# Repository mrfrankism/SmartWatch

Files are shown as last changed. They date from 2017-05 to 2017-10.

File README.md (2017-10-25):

## Welcome to my Smart Watch Project

This Project was started May 2017 and is still being worked on.
For more detailed Information check out the [wiki](https://github.com/mrfrankism/SmartWatch/wiki)

### Current Status:
* Currently the watch has undergone 2 prototypes.
* 2nd Prototype spin:


* The 2nd prototype was fabbed with the incorrecct package for the atmega328, so the 3rd spin will fix this issue without adding new       features for now
* Case for the watch is being designed to be 3D printed

### Initial goals for this project are:
* Working screen
* Actual simple watch functionality
* Computer to watch communication (SPI, UART)
* Bluetooth connectivity to phone 
* Notifications
* Probably going to need to make an app for full bluetooth-notification functionality
* Decent battery life (6 hours)
* Ability to charge easily from usb

### Extra goals:
* SOS signal - Being able to send a text with GPS coordinates to emergency contact, using only the watch 
* LTE connectivity
* Accelerometer
* Gyro
* Wifi?
* GPS

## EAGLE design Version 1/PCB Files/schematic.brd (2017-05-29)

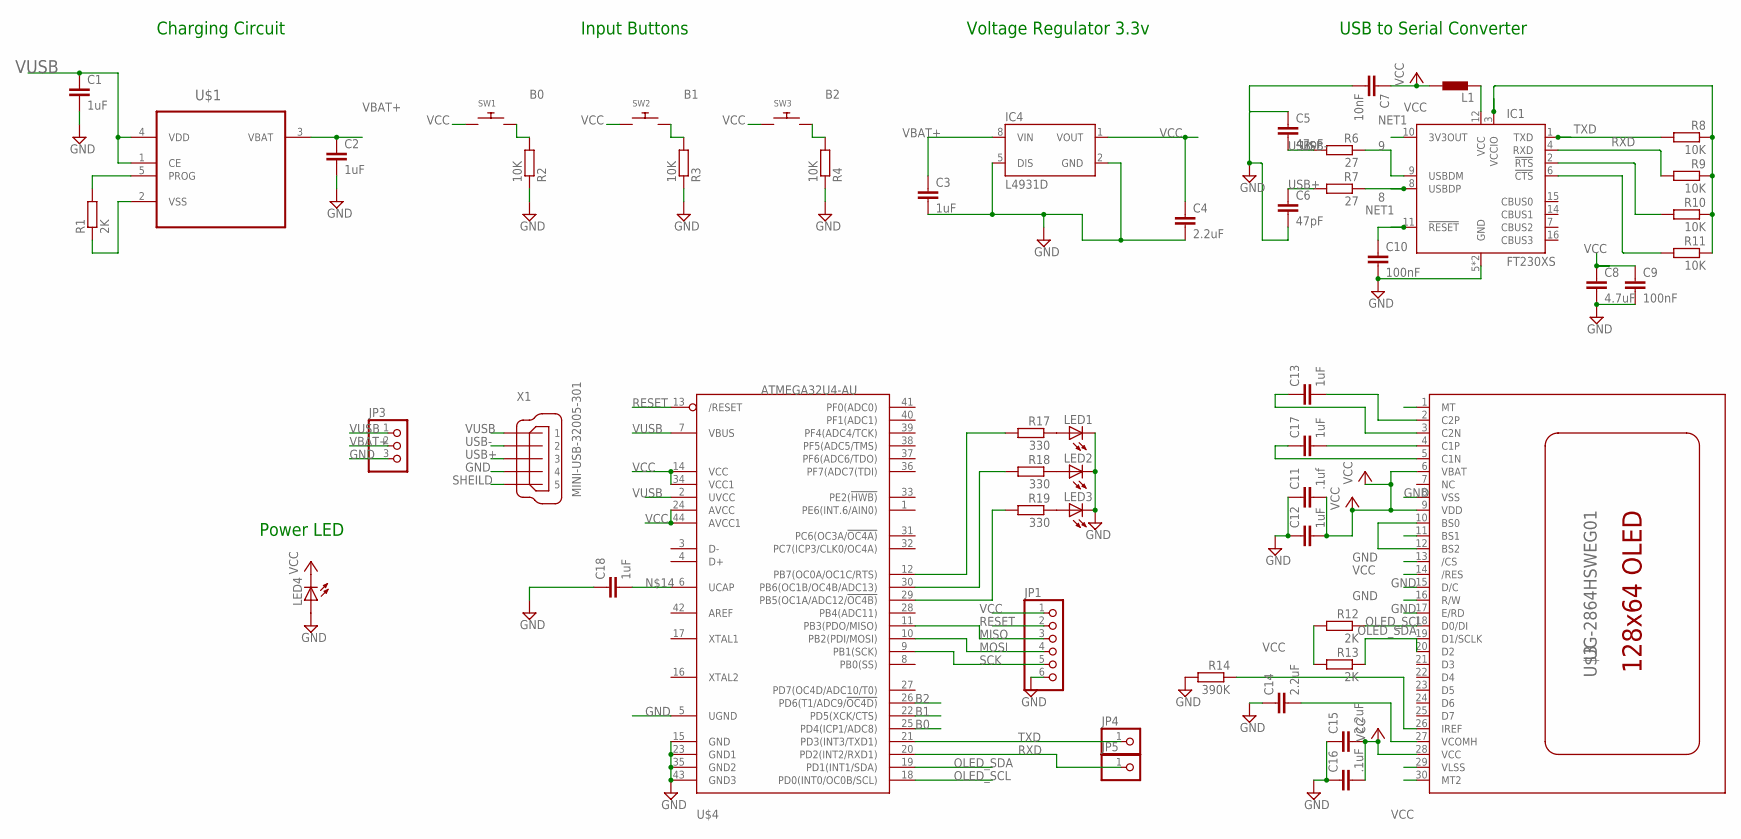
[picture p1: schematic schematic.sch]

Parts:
C1, C2, C3, C12, C13, C17, C18: 1uF; C0504
C4, C14, C15: 2.2uF; C0504
C5, C6: 47pF; C0504
C7: 10nF; C0504
C8: 4.7uF; C0504
C9, C10: 100nF; C0504
C11: .1uf; C0504
C16: .1uF; C0504
IC1: FT230XS; SSOP16
IC4: L4931D; SO08
JP1: PINHD-1X6B; 1X06-BIG
JP3: PINHD-1X3; 1X03
JP4, JP5: PINHD-1X1; 1X01
L1: BLM15HB221SN1; 0402
LED1, LED2, LED3, LED4: LEDSMT1206; 1206
R1, R12, R13: 2K; R0603
R2, R3, R4, R8, R9, R10, R11: 10K; R0603
R6, R7: 27; R0603
R14: 390K; R0603
R17, R18, R19: 330; R0603
SW1, SW2, SW3: SWITCH_PUSHBUTTONSOFTTOUCHSMD_SJ; PUSHBUTTON_SMD_SJ
U$1: MCP73812T-420I/OT; SOT95P270X145-5N
U$3: UG-2864HSWEG01; 1X30-0.7MM
U$4: ATMEGA32U4-AU; TQFP44
X1: MINI-USB-32005-301; 32005-301

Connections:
8: IC1.8 (USBDP), R7.1
9: IC1.9 (USBDM), R6.1
B0: R2.2, SW1.P$2, U$4.25 (PD4(ICP1/ADC8))
B1: R3.2, SW2.P$2, U$4.22 (PD5(XCK/CTS))
B2: R4.2, SW3.P$2, U$4.26 (PD6(T1/ADC9/!OC4D))
FTDI_VCC: IC1.12 (VCC), L1.1
GND: C1.2, C2.2, C3.2, C4.2, C5.1, C6.2, C7.2, C8.2, C9.2, C10.2, C11.1, C12.1, C14.1, C15.1, C16.1, C18.1, IC1.5 (GND), IC1.13 (GND), IC4.2 (GND), IC4.5 (DIS), JP1.6, JP3.3, LED1.C, LED2.C, LED3.C, LED4.A, R2.1, R3.1, R4.1, R14.2, U$3.1 (MT), U$3.8 (VSS), U$3.10 (BS0), U$3.12 (BS2), U$3.13 (/CS), U$3.15 (D/C), U$3.16 (R/W), U$3.17 (E/RD), U$3.29 (VLSS), U$3.30 (MT2), U$4.5 (UGND), U$4.15 (GND), U$4.23 (GND1), U$4.35 (GND2), U$4.43 (GND3), X1.4
MISO: JP1.3, U$4.11 (PB3(PDO/MISO))
MOSI: JP1.4, U$4.10 (PB2(PDI/MOSI))
unnamed: R1.2, U$1.5 (PROG)
unnamed: R1.1, U$1.2 (VSS)
unnamed: C14.2, U$3.27 (VCOMH)
unnamed: IC1.2 (!RTS), R10.2
unnamed: C13.2, U$3.2 (C2P)
unnamed: IC1.6 (!CTS), R11.2
unnamed: R14.1, U$3.26 (IREF)
unnamed: C13.1, U$3.3 (C2N)
unnamed: C17.2, U$3.4 (C1P)
unnamed: C17.1, U$3.5 (C1N)
unnamed: C18.2, U$4.6 (UCAP)
unnamed: LED1.A, R17.1
unnamed: LED2.A, R18.1
unnamed: LED3.A, R19.1
unnamed: R19.2, U$4.29 (PB5(OC1A/ADC12/!OC4B))
unnamed: R18.2, U$4.30 (PB6(OC1B/OC4B/ADC13))
unnamed: R17.2, U$4.12 (PB7(OC0A/OC1C/RTS))
NET1: C10.1, IC1.3 (VCCIO), IC1.10 (3V3OUT), IC1.11 (!RESET), R8.1, R9.1, R10.1, R11.1
OLED_SCL: R12.1, U$3.18 (D0/DI), U$4.18 (PD0(INT0/OC0B/SCL))
OLED_SDA: R13.1, U$3.19 (D1/SCLK), U$3.20 (D2), U$4.19 (PD1(INT1/SDA))
RESET: JP1.2, U$4.13 (/RESET)
RXD: IC1.4 (RXD), JP5.1, R9.2, U$4.20 (PD2(INT2/RXD1))
SCK: JP1.5, U$4.9 (PB1(SCK))
SHEILD: X1.5
TXD: IC1.1 (TXD), JP4.1, R8.2, U$4.21 (PD3(INT3/TXD1))
USB+: C6.1, R7.2, X1.3
USB-: C5.2, R6.2, X1.2
VBAT+: C2.1, C3.1, IC4.8 (VIN), JP3.2, U$1.3 (VBAT)
VCC: C4.1, C7.1, C8.1, C9.1, C11.2, C12.2, C15.2, C16.2, IC4.1 (VOUT), JP1.1, L1.2, LED4.C, R12.2, R13.2, SW1.P$1, SW2.P$1, SW3.P$1, U$3.6 (VBAT), U$3.9 (VDD), U$3.11 (BS1), U$3.14 (/RES), U$3.28 (VCC), U$4.14 (VCC), U$4.24 (AVCC), U$4.34 (VCC1), U$4.44 (AVCC1)
VUSB: C1.1, JP3.1, U$1.1 (CE), U$1.4 (VDD), U$4.2 (UVCC), U$4.7 (VBUS), X1.1

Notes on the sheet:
Charging Circuit
Input Buttons
Voltage Regulator 3.3v
USB to Serial Converter
Power LED

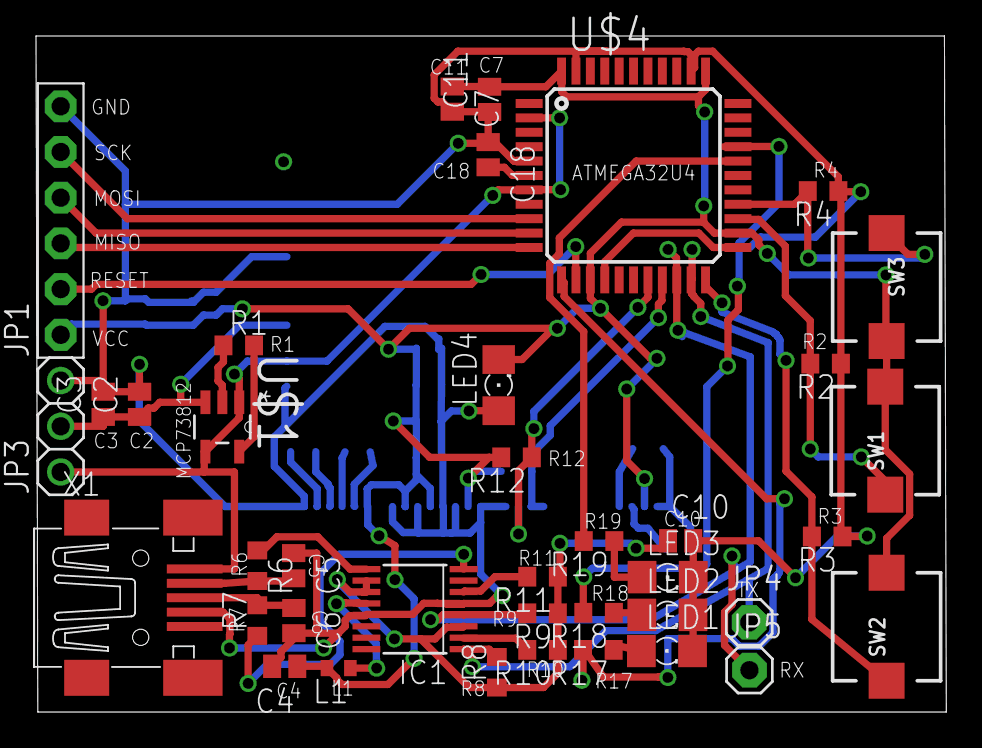
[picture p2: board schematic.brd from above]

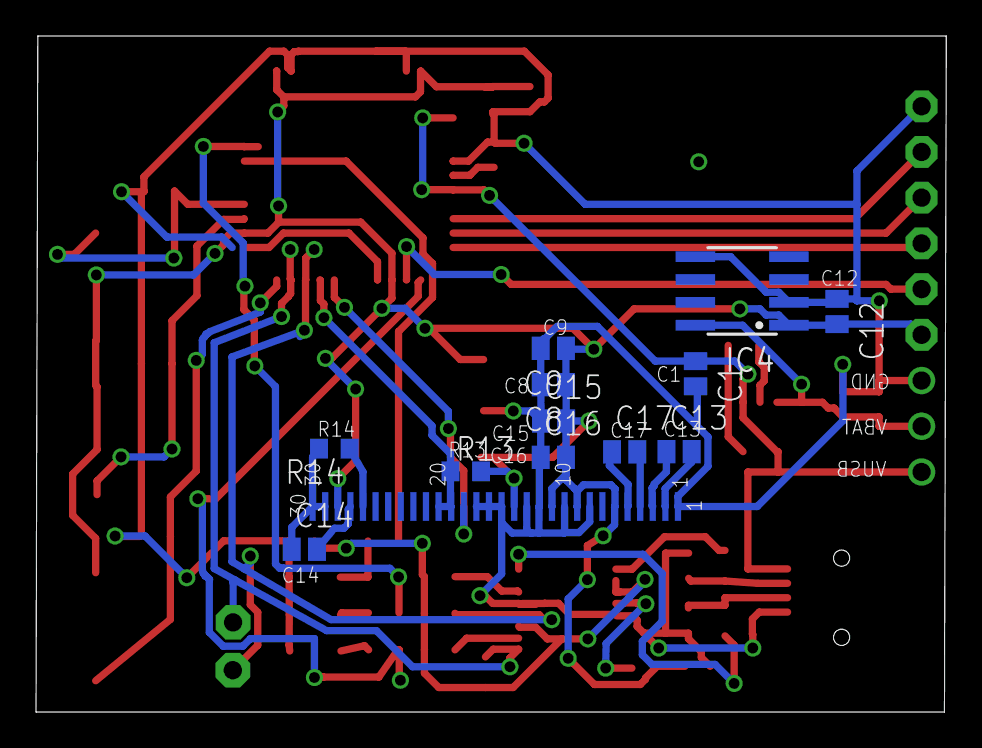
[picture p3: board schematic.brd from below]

Board: 2 copper layers, 50.6 x 37.6 mm, 52 parts (13 on the bottom side), 38 nets.

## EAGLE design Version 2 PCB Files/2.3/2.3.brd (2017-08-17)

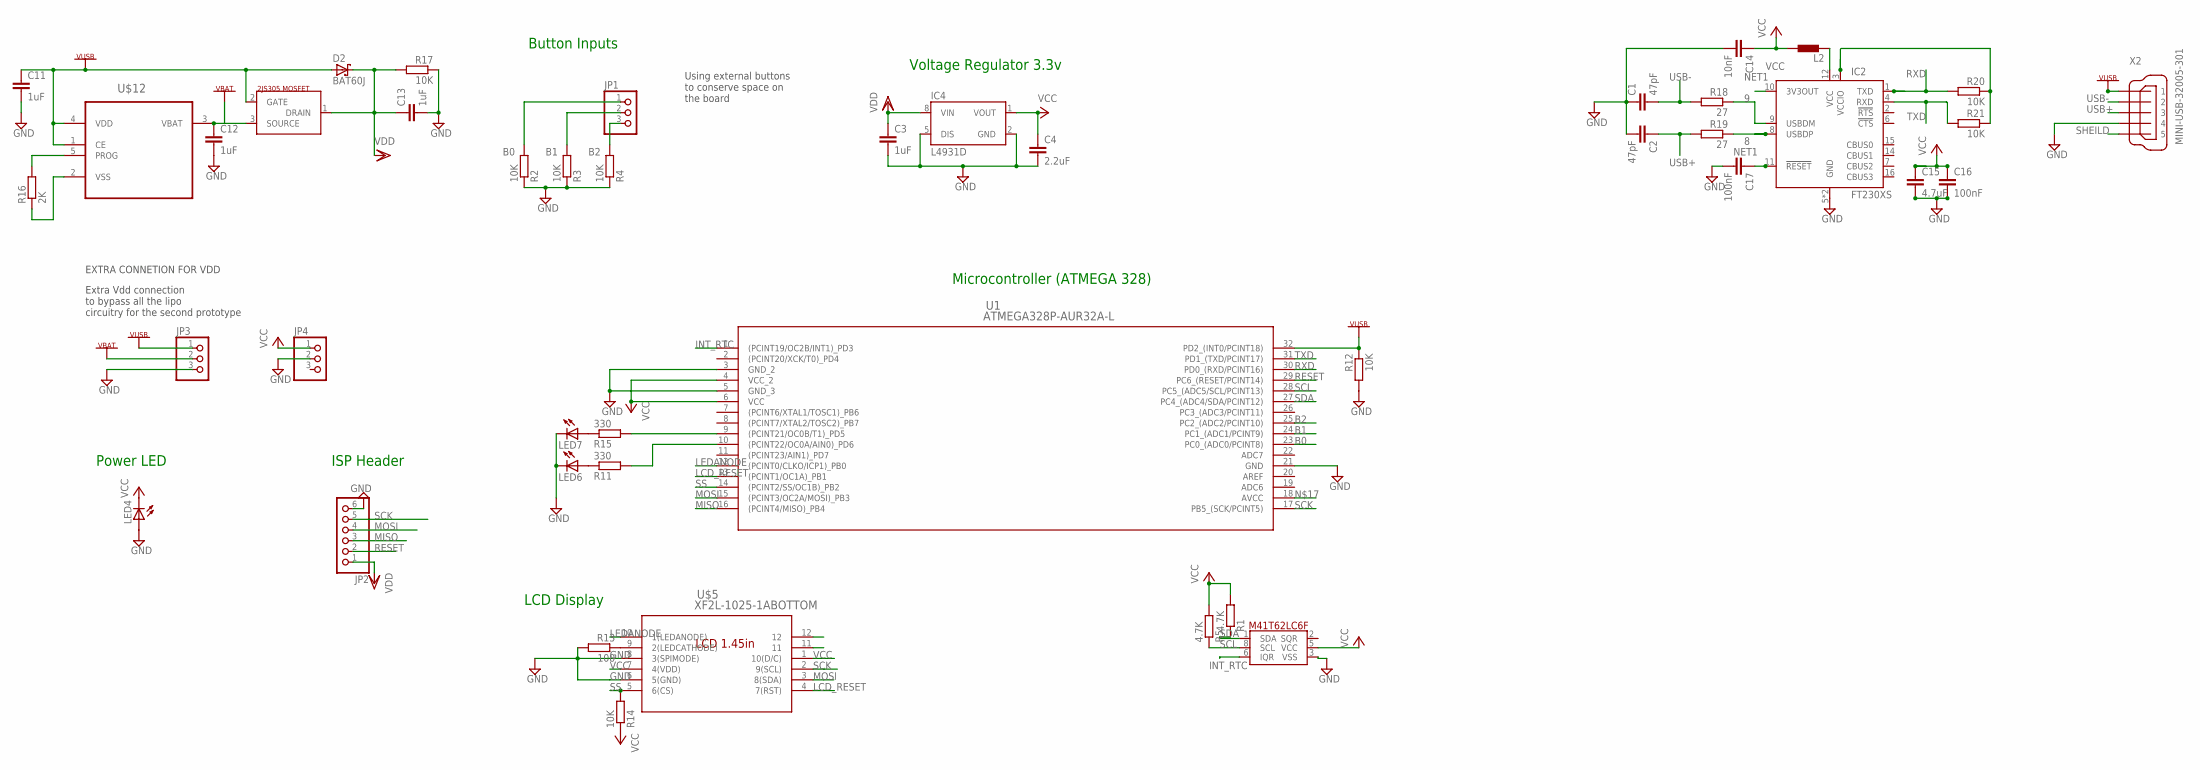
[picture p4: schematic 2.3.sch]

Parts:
C1, C2: 47pF; C0603K
C3, C11, C12, C13: 1uF; C0603K
C4: 2.2uF; C0603K
C14: 10nF; C0603K
C15: 4.7uF; C0603K
C16, C17: 100nF; C0603K
D2: BAT60J; SOD323_ST
IC2: FT230XS; SSOP16
IC4: L4931D; SO08
JP1, JP3, JP4: PINHD-1X3CB; 1X03-CLEANBIG
JP2: PINHD-1X6B; 1X06-BIG
L2: BLM15HB221SN1; 0402
LED4, LED6, LED7: LEDSMT1206; 1206
R1, R5: 4.7K; R0603
R2, R3, R4, R12, R14, R17, R20, R21: 10K; R0603
R11, R15: 330; R0603
R13: 100; R0603
R16: 2K; R0603
R18, R19: 27; R0603
U1: ATMEGA328P-AUR32A-L; 32A-L
U$1: M41T62LC6F; LCC-8
U$5: XF2L-1025-1ABOTTOM; CON10_1X10_DBR_XF2L
U$12: MCP73812T-420I/OT; SOT95P270X145-5N
U$13: 2JS305; SOT346-R
X2: MINI-USB-32005-301; 32005-301

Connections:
8: IC2.8 (USBDP), R19.1
9: IC2.9 (USBDM), R18.1
B0: JP1.1, R2.2, U1.23 (PC0_(ADC0/PCINT8))
B1: JP1.2, R3.2, U1.24 (PC1_(ADC1/PCINT9))
B2: JP1.3, R4.2, U1.25 (PC2_(ADC2/PCINT10))
GND: C1.1, C2.2, C3.2, C4.2, C11.2, C12.2, C13.2, C14.2, C15.2, C16.2, C17.2, IC2.5 (GND), IC2.13 (GND), IC4.2 (GND), IC4.5 (DIS), JP2.6, JP3.3, JP4.2, LED4.A, LED6.C, LED7.C, R2.1, R3.1, R4.1, R12.2, R13.2, R17.1, U1.3 (GND_2), U1.5 (GND_3), U1.21 (GND), U$1.3 (VSS), U$5.6 (5(GND)), U$5.8 (3(SPIMODE)), X2.4
INT_RTC: U1.1 ((PCINT19/OC2B/INT1)_PD3), U$1.6 (IQR)
LCD_RESET: U1.13 ((PCINT1/OC1A)_PB1), U$5.4 (7(RST))
LEDANODE: U1.12 ((PCINT0/CLKO/ICP1)_PB0), U$5.10 (1(LEDANODE))
MISO: JP2.3, U1.16 ((PCINT4/MISO)_PB4)
MOSI: JP2.4, U1.15 ((PCINT3/OC2A/MOSI)_PB3), U$5.3 (8(SDA))
unnamed: R13.1, U$5.9 (2(LEDCATHODE))
unnamed: IC2.12 (VCC), L2.1
unnamed: R15.2, U1.9 ((PCINT21/OC0B/T1)_PD5)
unnamed: R16.2, U$12.5 (PROG)
unnamed: R16.1, U$12.2 (VSS)
unnamed: LED6.A, R11.1
unnamed: LED7.A, R15.1
unnamed: R11.2, U1.10 ((PCINT22/OC0A/AIN0)_PD6)
NET1: C17.1, IC2.3 (VCCIO), IC2.10 (3V3OUT), IC2.11 (!RESET), R20.1, R21.1
RESET: JP2.2, U1.29 (PC6_(RESET/PCINT14))
RXD: IC2.1 (TXD), R20.2, U1.30 (PD0_(RXD/PCINT16))
SCK: JP2.5, U1.17 (PB5_(SCK/PCINT5)), U$5.2 (9(SCL))
SCL: R5.1, U1.28 (PC5_(ADC5/SCL/PCINT13)), U$1.8 (SCL)
SDA: R1.1, U1.27 (PC4_(ADC4/SDA/PCINT12)), U$1.1 (SDA)
SHEILD: X2.5
SS: R14.2, U1.14 ((PCINT2/SS/OC1B)_PB2), U$5.5 (6(CS))
TXD: IC2.4 (RXD), R21.2, U1.31 (PD1_(TXD/PCINT17))
USB+: C2.1, R19.2, X2.3
USB-: C1.2, R18.2, X2.2
VBAT: C12.1, JP3.2, U$12.3 (VBAT), U$13.3 (SOURCE)
VCC: C4.1, C14.1, C15.1, C16.1, IC4.1 (VOUT), JP4.1, L2.2, LED4.C, R1.2, R5.2, R14.1, U1.4 (VCC_2), U1.6 (VCC), U$1.5 (VCC), U$5.1 (10(D/C)), U$5.7 (4(VDD))
VDD: C3.1, C13.1, D2.C, IC4.8 (VIN), JP2.1, R17.2, U$13.1 (DRAIN)
VUSB: C11.1, D2.A, JP3.1, R12.1, U1.32 (PD2_(INT0/PCINT18)), U$12.1 (CE), U$12.4 (VDD), U$13.2 (GATE), X2.1

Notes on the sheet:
Button Inputs
Voltage Regulator 3.3v
Power LED
EXTRA CONNETION FOR VDD
Extra Vdd connection to bypass all the lipo circuitry for the second prototype
ISP Header
Microcontroller (ATMEGA 328)
LCD Display
Using external buttons to conserve space on the board

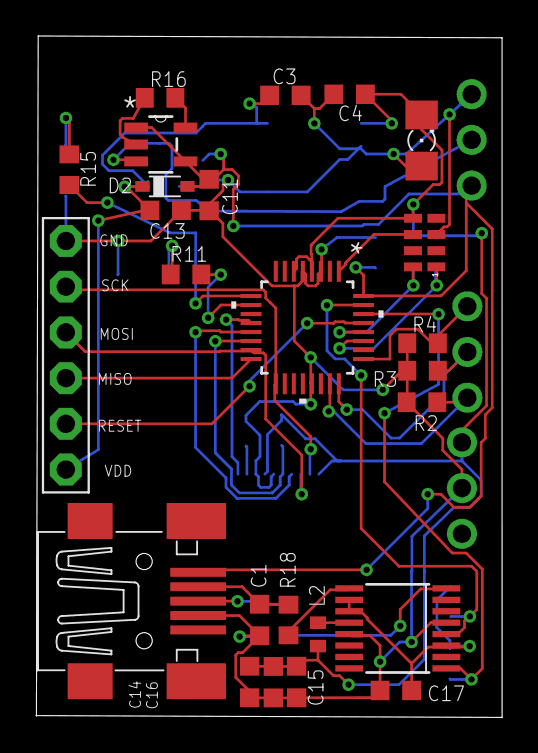
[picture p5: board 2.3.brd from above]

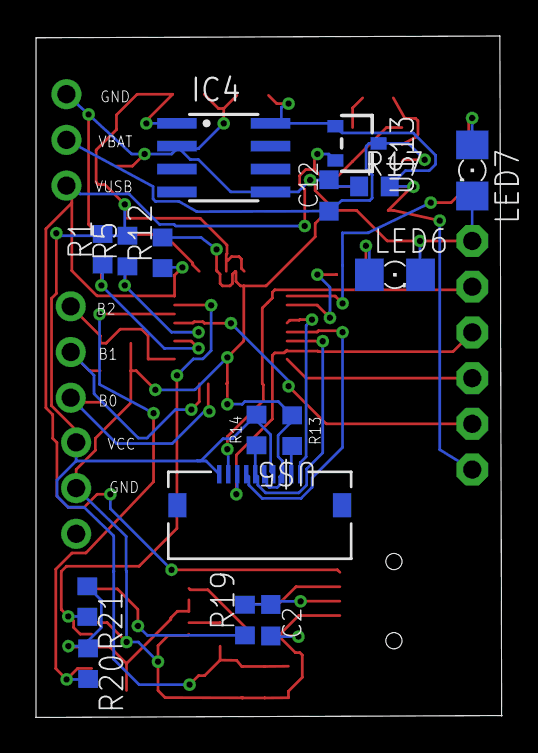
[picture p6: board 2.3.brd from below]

Board: 2 copper layers, 25.9 x 37.9 mm, 44 parts (16 on the bottom side), 33 nets.

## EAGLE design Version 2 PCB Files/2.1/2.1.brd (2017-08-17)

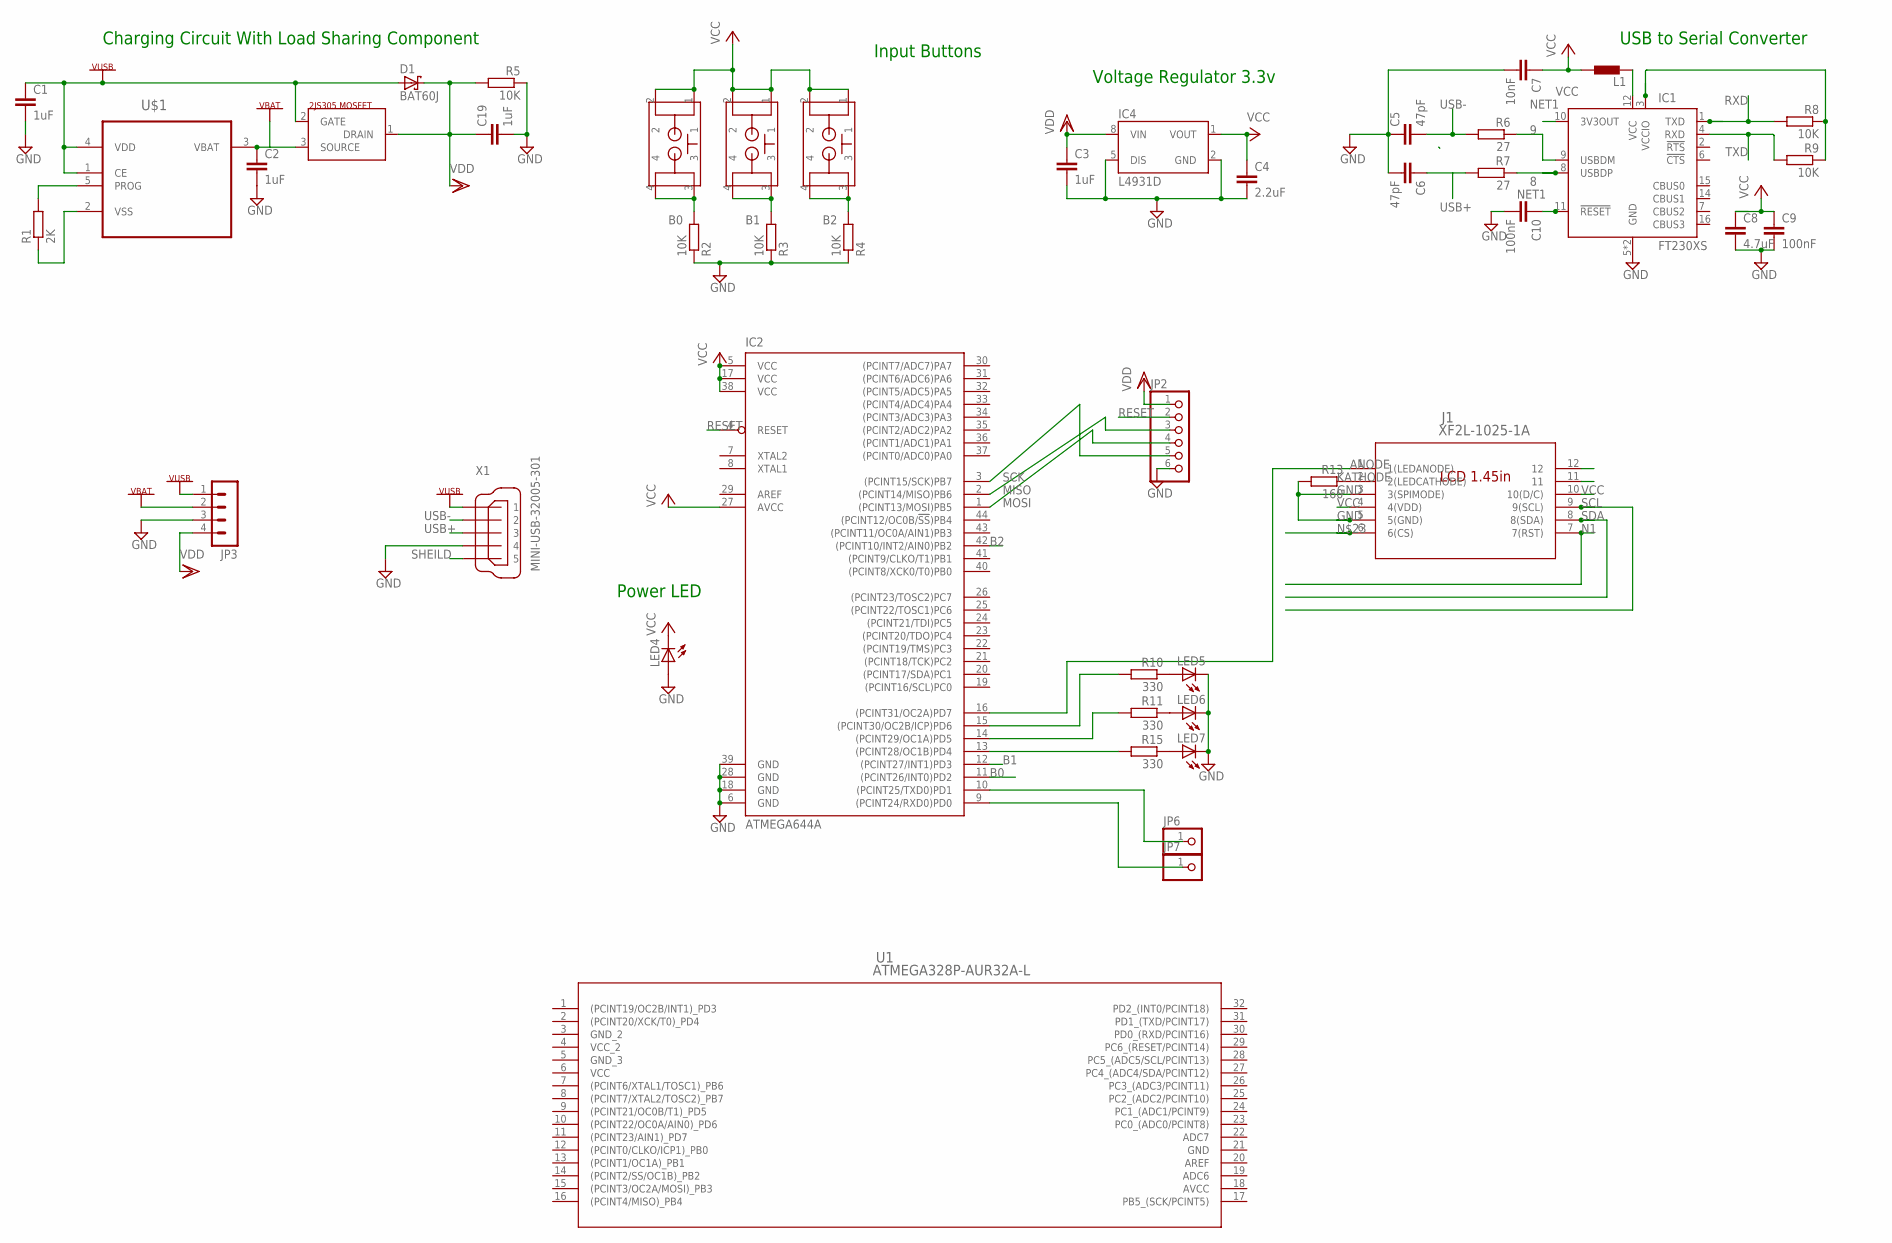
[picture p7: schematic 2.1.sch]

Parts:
C1, C2, C3, C19: 1uF; C0603K
C4: 2.2uF; C0603K
C5, C6: 47pF; C0603K
C7: 10nF; C0603K
C8: 4.7uF; C0603K
C9, C10: 100nF; C0603K
D1: BAT60J; SOD323_ST
IC1: FT230XS; SSOP16
IC2: ATMEGA644A; TQFP44
IC4: L4931D; SO08
J1: XF2L-1025-1A; CON10_1X10_DBR_XF2L
JP2: PINHD-1X6B; 1X06-BIG
JP3: MA04-1
JP6, JP7: PINHD-1X1; 1X01
L1: BLM15HB221SN1; 0402
LED4, LED5, LED6, LED7: LEDSMT1206; 1206
R1: 2K; R0603
R2, R3, R4, R5, R8, R9: 10K; R0603
R6, R7: 27; R0603
R10, R11, R15: 330; R0603
R13: 160; R0603
U1: ATMEGA328P-AUR32A-L; 32A-L
U$1: MCP73812T-420I/OT; SOT95P270X145-5N
U$2: 2JS305; SOT346-R
U$3, U$4, U$11: TL3315NF100Q; TL3315NF100Q-PACKAGE
X1: MINI-USB-32005-301; 32005-301

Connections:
8: IC1.8 (USBDP), R7.1
9: IC1.9 (USBDM), R6.1
ANODE: IC2.16 ((PCINT31/OC2A)PD7), J1.1 (1(LEDANODE))
AVCC: U1.18 (AVCC)
B0: IC2.11 ((PCINT26/INT0)PD2), R2.2, U$3.3, U$3.4
B1: IC2.12 ((PCINT27/INT1)PD3), R3.2, U$4.3, U$4.4
B2: IC2.42 ((PCINT10/INT2/AIN0)PB2), R4.2, U$11.3, U$11.4
FTDI_VCC: IC1.12 (VCC), L1.1
GND: C1.2, C2.2, C3.2, C4.2, C5.1, C6.2, C7.2, C8.2, C9.2, C10.2, C19.2, IC1.5 (GND), IC1.13 (GND), IC2.6 (GND), IC2.18 (GND), IC2.28 (GND), IC2.39 (GND), IC4.2 (GND), IC4.5 (DIS), J1.3 (3(SPIMODE)), J1.5 (5(GND)), JP2.6, JP3.3, LED4.A, LED5.C, LED6.C, LED7.C, R2.1, R3.1, R4.1, R5.1, R13.2, U1.21 (GND), X1.4
GND_2: U1.3 (GND_2)
GND_3: U1.5 (GND_3)
KATHODE: J1.2 (2(LEDCATHODE)), R13.1
MISO: IC2.2 ((PCINT14/MISO)PB6), JP2.3
MOSI: IC2.1 ((PCINT13/MOSI)PB5), JP2.4
N1: J1.7 (7(RST))
unnamed: R1.2, U$1.5 (PROG)
unnamed: R1.1, U$1.2 (VSS)
unnamed: LED5.A, R10.1
unnamed: LED6.A, R11.1
unnamed: LED7.A, R15.1
unnamed: IC2.13 ((PCINT28/OC1B)PD4), R15.2
unnamed: IC2.14 ((PCINT29/OC1A)PD5), R11.2
unnamed: IC2.15 ((PCINT30/OC2B/ICP)PD6), R10.2
unnamed: IC2.10 ((PCINT25/TXD0)PD1), JP6.1
NET1: C10.1, IC1.3 (VCCIO), IC1.10 (3V3OUT), IC1.11 (!RESET), R8.1, R9.1
RESET: IC2.4 (RESET), JP2.2
RXD: IC1.1 (TXD), R8.2
RXD1: IC2.9 ((PCINT24/RXD0)PD0), JP7.1
SCK: IC2.3 ((PCINT15/SCK)PB7), JP2.5
SCL: J1.9 (9(SCL))
SDA: J1.8 (8(SDA))
SHEILD: X1.5
TXD: IC1.4 (RXD), R9.2
USB+: C6.1, R7.2, X1.3
USB-: C5.2, R6.2, X1.2
VBAT: C2.1, JP3.2, U$1.3 (VBAT), U$2.3 (SOURCE)
VCC: C4.1, C7.1, C8.1, C9.1, IC2.5 (VCC), IC2.17 (VCC), IC2.27 (AVCC), IC2.38 (VCC), IC4.1 (VOUT), J1.4 (4(VDD)), J1.10 (10(D/C)), L1.2, LED4.C, U1.6 (VCC), U$3.1, U$3.2, U$4.1, U$4.2, U$11.1, U$11.2
VCC_2: U1.4 (VCC_2)
VDD: C3.1, C19.1, D1.C, IC4.8 (VIN), JP2.1, JP3.4, R5.2, U$2.1 (DRAIN)
VUSB: C1.1, D1.A, JP3.1, U$1.1 (CE), U$1.4 (VDD), U$2.2 (GATE), X1.1

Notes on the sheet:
Charging Circuit With Load Sharing Component
Input Buttons
Voltage Regulator 3.3v
USB to Serial Converter
Power LED

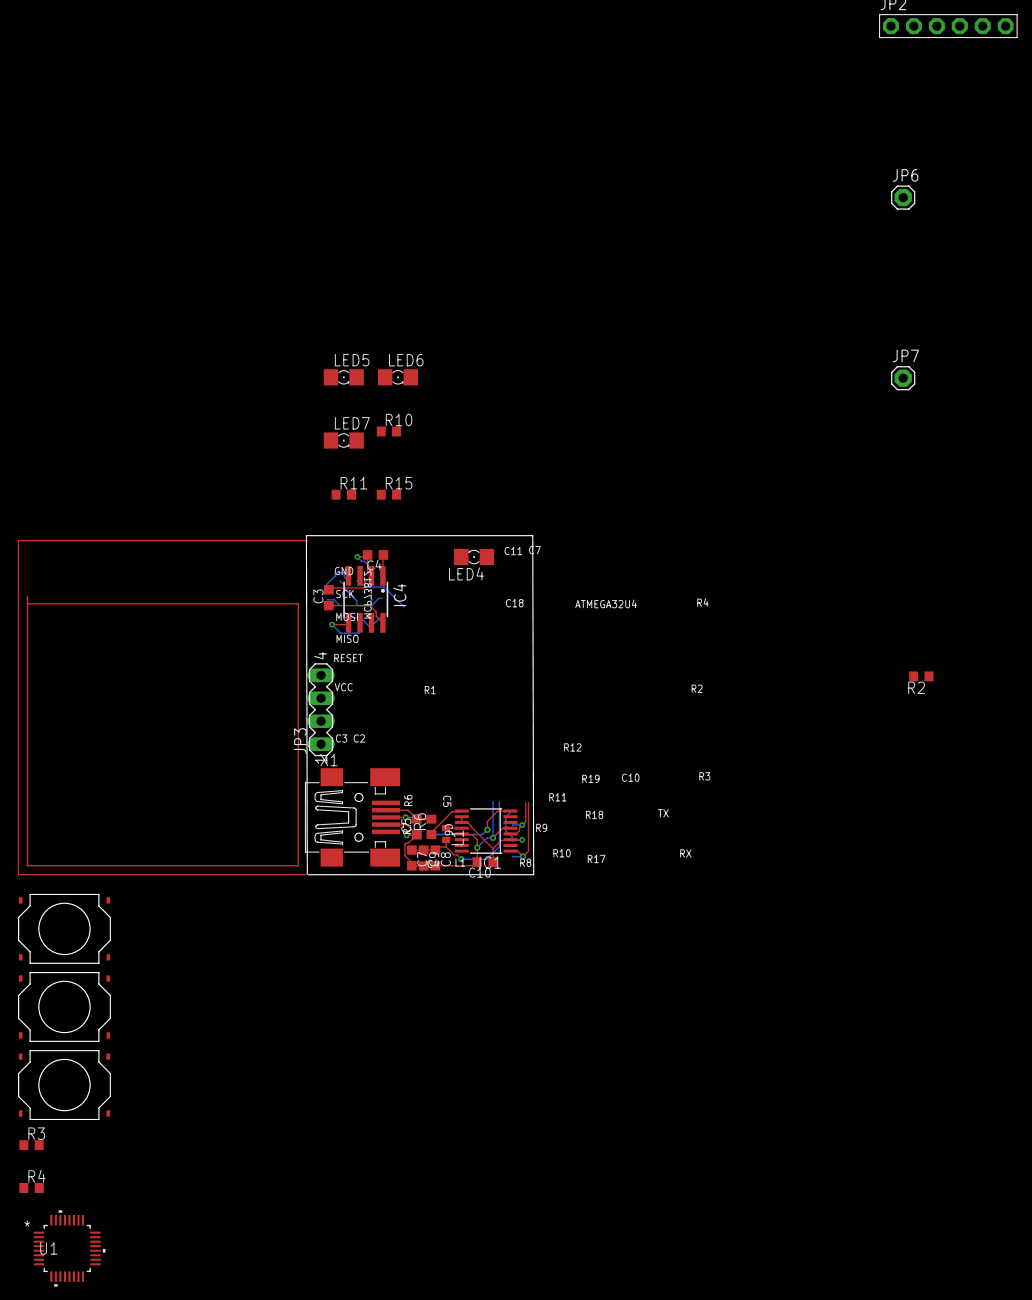
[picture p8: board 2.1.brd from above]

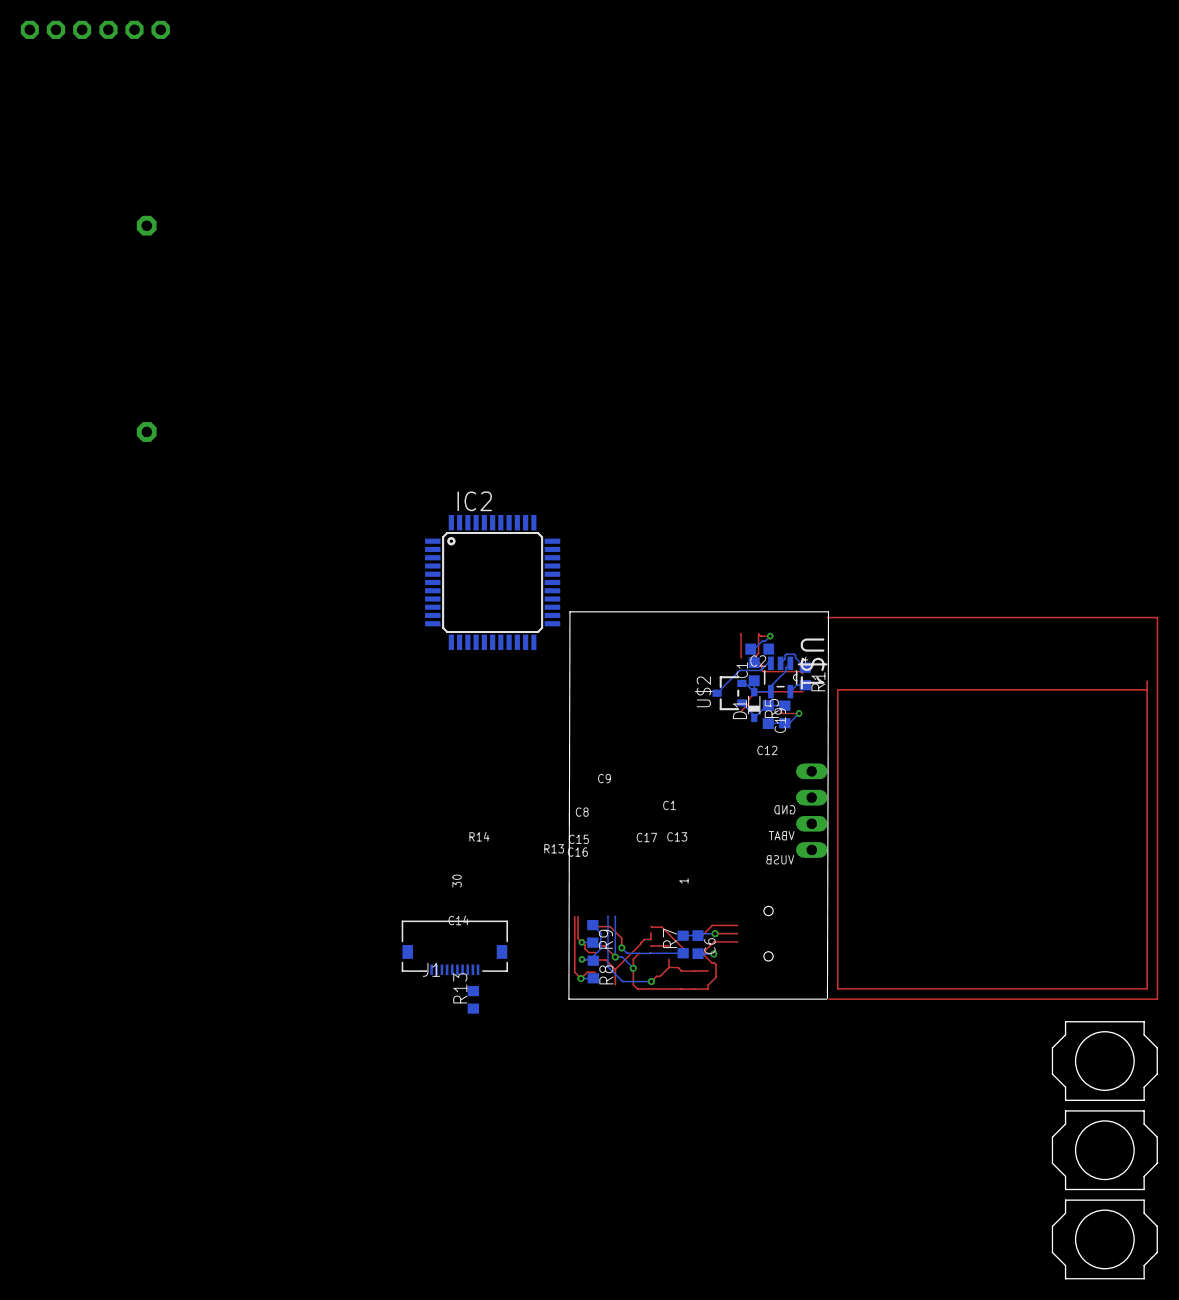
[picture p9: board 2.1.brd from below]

Board: 2 copper layers, 45 parts (15 on the bottom side), 32 nets.

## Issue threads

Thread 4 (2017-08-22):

2nd Prototype had wrong package size

mrfrankism, 2017-08-22:
The package size was significantly smaller that it should have been and cant take the micro controller package I have, Going to have to fix the board layout and, resend to fab.

Also need to organize components I have right now and order what I need for next spin, make sure to order 3 more of every part that seems to be the best approach to not over order, but have extra components just in case
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

Closed 2017-10-25.

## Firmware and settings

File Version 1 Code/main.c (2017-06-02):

#include <avr/io.h>
#include <avr/delay.h>
#include "USART.h"
//#include "oled_lib.h"
/* Main file to control the first version of the OLED watch
	Creator:Franco Baudino
*/

 	//PIN DEFINITIONS

#define LED1 B, 5
#define LED2 B, 6
#define LED3 B, 7

#define BTN1 D, 5
#define BTN2 D, 6
#define BTN3 D, 7



// MACROS
#define PORT(port, pin) (PORT ## port)
#define PIN(port, pin) (pin)
#define DDR(port, pin) (DDR ## port)

#define set_output(io) (DDR(io) |= (1<<PIN(io)))
#define toggle(io) (PORT(io) ^= (1<<PIN(io)))
#define set_low(io) (PORT(io) |= (0<<PIN(io)))
#define set_high(io) (PORT(io) |= (1<<PIN(io)))

//test_UART(): Sends and recieves a byte and lights LEDS PB5 and PB6 when both tests pass
//Status : Code for RX needs to be implemented
void test_UART(void){
//	transmit_byte("A");
	//toggle(LED1);
	//_delay_ms(1000);
	//transmitByte(15);
	//CODE FOR RX TEST GOES HERE
//toggle(LED1);
transmitByte(65);
//_delay_ms(300);
//toggle(LED1);
//_delay_ms(300);
	//toggle(LED1);

}

void test_buttons(void){
	PORTB |= (PIND & (1<<5)) | (PIND & (1<<6)) | (PIND & (1<<7));
}

//test_LEDS: Tests the three onboard LEDs to see if they work
//Status: Done
void test_LEDS(void){
		toggle(LED1);
	//	set_high(LED2);
	//	set_high(LED3);
		_delay_ms(1000);
		toggle(LED1);
	//	set_low(LED2);
	//	set_low(LED3);
		_delay_ms(1000);
}


int main(void){
	//set LEDs to output
	set_output(LED1);
	set_output(LED2);
	set_output(LED3);

	toggle(BTN1); //turn btn1 pullup resistor off
	
	//start serial com for testing
	init_UART();

	while(1){
		//test_LEDS();
		//test_UART();
		//test_LEDS();
		test_buttons();
		//_delay_ms(1000);
		}

	return 0;
}

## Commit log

2017-05-16 First Push
    [schematic.brd, schematic.sch]
2017-05-17 saving to git
    [schematic.brd, schematic.sch]
2017-05-21 Finished layout V1
    [schematic.brd, schematic.sch]
2017-05-21 Checked and fixed with OSH Park DRC
    [schematic.brd, schematic.sch]
2017-05-21 Added Power LED, passed DRC
    [schematic.brd, schematic.sch]
2017-05-22 Added a version 1 folder, all upcomming work will be in a version 2 folder for the next prototype run
    [schematic.brd, schematic.sch]
2017-06-02 Changing up file structure
    [schematic.brd, schematic.sch]
2017-06-03 Started V2 Schematic, need to put in smaller buttons, etc
2017-07-26 Added a way to bypass LIPO charging circuitry which wont be ready for the next prototype
    [2.1.brd, 2.1.sch]
2017-08-07 Need to layout board and send to fab
    Switched to the atmega 328 for simplicity and size, well see what happens, should add an rtc to the board, or a spi header to test the i2c with
    [2.1.brd, 2.2.brd, 2.2.sch]
2017-08-17 Version 2.2 Is finished!
    Sent the board to the fab waiting for it.
    [2.1.brd, 2.2.brd, 2.2.sch]
2017-08-18 Working on Presentation and Organizing
    [2.3.brd, 2.3.sch, schematic.brd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]
2017-08-22 Updating Current Status
2017-10-15 Changed the Atmega 328 to the correct package size
    [2.4.brd, 2.4.sch]
2017-10-16 Routed the board with the new Atmega package on it
